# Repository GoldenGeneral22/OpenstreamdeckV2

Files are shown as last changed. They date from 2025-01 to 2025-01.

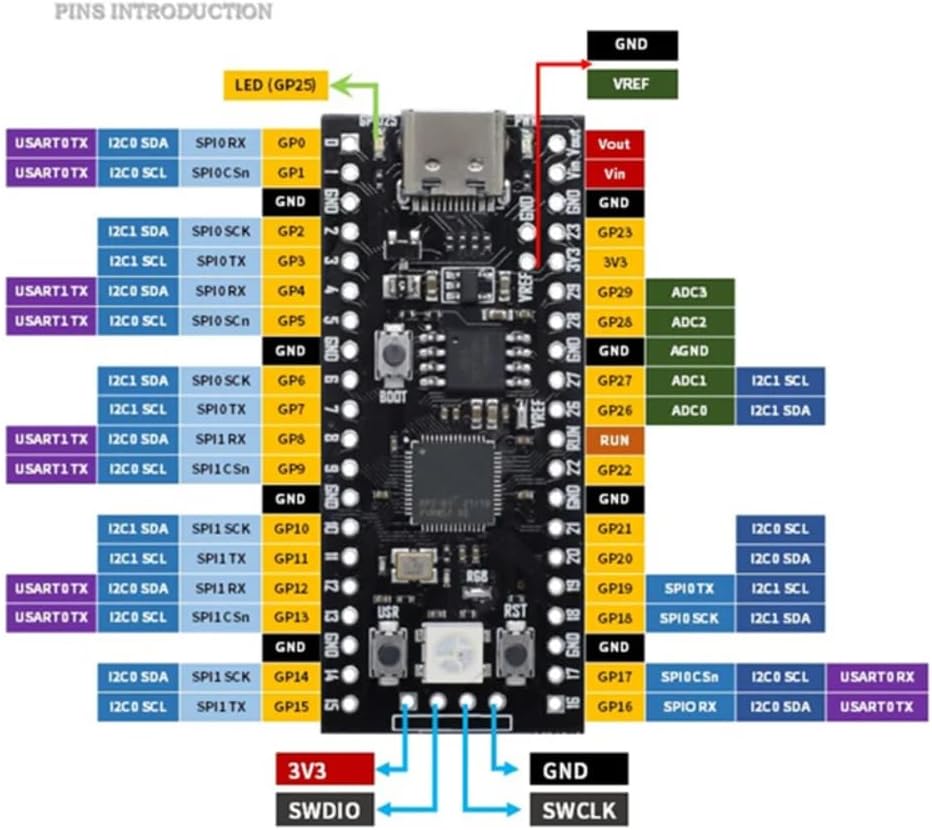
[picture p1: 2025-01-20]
Hardware/General/Dollatek Pinout.jpg

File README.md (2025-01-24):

# OpenstreamdeckV2: modular and open-source
A modular open-source 3D-printable Version of the Elgato streamdeck using 6 cherry-mx-style keyswitches(F13-F18) and a pressable KY-040 rotary encoder(volume increase, volume decrease, volume mute) as well as a RP2040 Microcontroller running circuitpython.

The area is divided into one bigger rectancular modul, used for the keyswitches and one smaller square modul, used for the rotary encoder.

To increase modularity and repairability only Jumper-Cables were used to connect to the RP2040 Microcontroller.

## External Works used:
### Software
Circuit diagram software used https://fritzing.org/

HID-Library used https://github.com/adafruit/Adafruit_CircuitPython_HID

USB-Library used https://docs.circuitpython.org/en/latest/shared-bindings/usb_hid/

### Hardware
RP2040 Microcontroller used https://amzn.eu/d/6dbKLKC

KY-040 rotary encoders used https://amzn.eu/d/2rxxnzF

Keyswitches used https://amzn.eu/d/dNDsguh

also used m3 screws, m3 thread inserts, female-to-female jumper cables, 3mm blue LEDs and resistors for the LEDs

### 3D-Prints
blank keycaps used https://www.thingiverse.com/thing:4186055 from CDante on Thingiverse.

encoder knob used https://www.thingiverse.com/thing:2797118 from tsw on Thingiverse.

The specific keycaps, the case and the modules were my own creation.

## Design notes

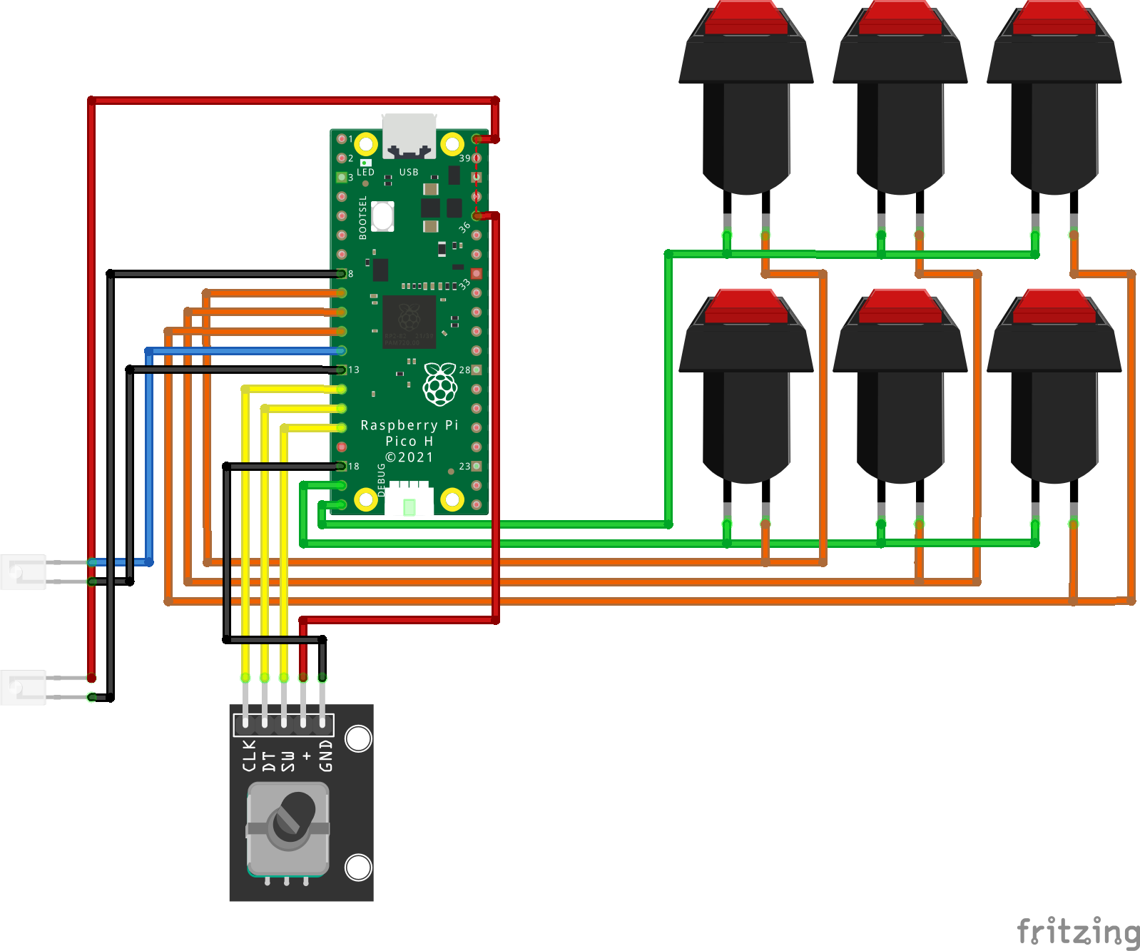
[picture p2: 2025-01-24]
Hardware/Circuit diagram/streamdeck_Steckplatine.png

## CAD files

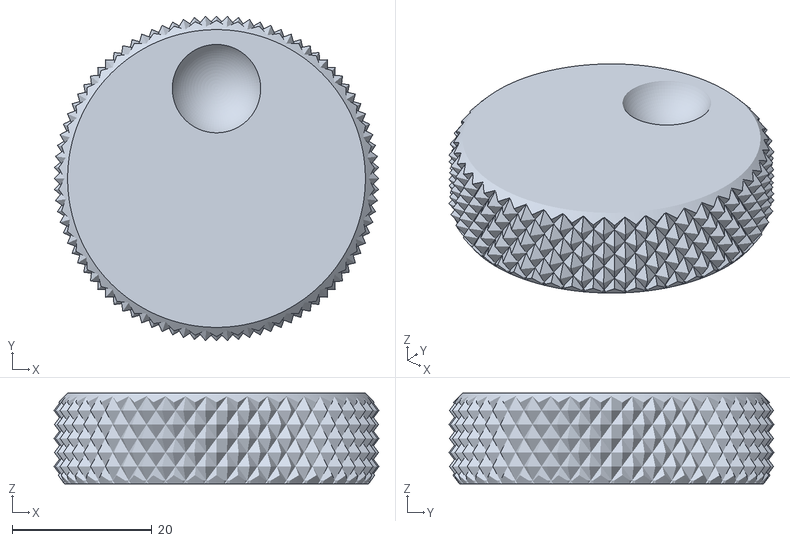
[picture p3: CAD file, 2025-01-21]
Hardware/3D Prints/EncoderKnob/rotary-encoder-knob_knurled.stl
46.5 x 46.5 x 13.0

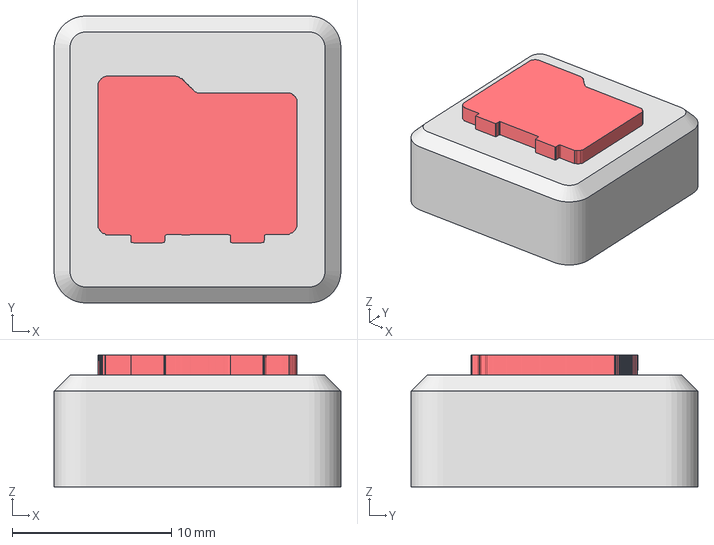
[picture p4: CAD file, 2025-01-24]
Hardware/3D Prints/Keycaps/Explorer Keycap.3mf
18.0 x 18.0 x 8.26 mm

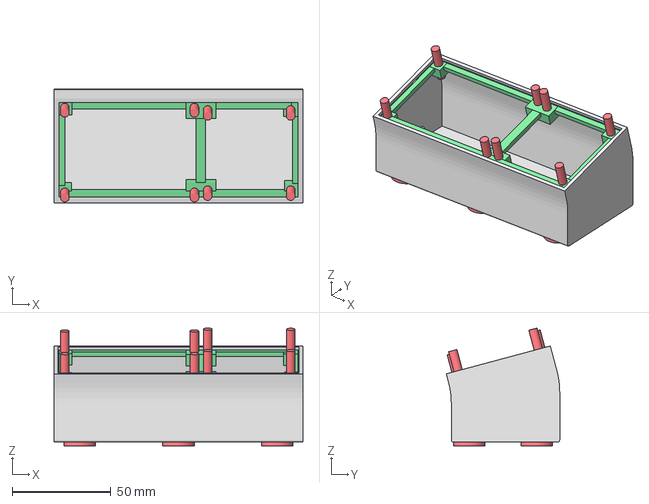
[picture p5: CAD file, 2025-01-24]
Hardware/3D Prints/MountingCase/CasePrototype v3.3mf
126.0 x 57.4 x 59.7 mm

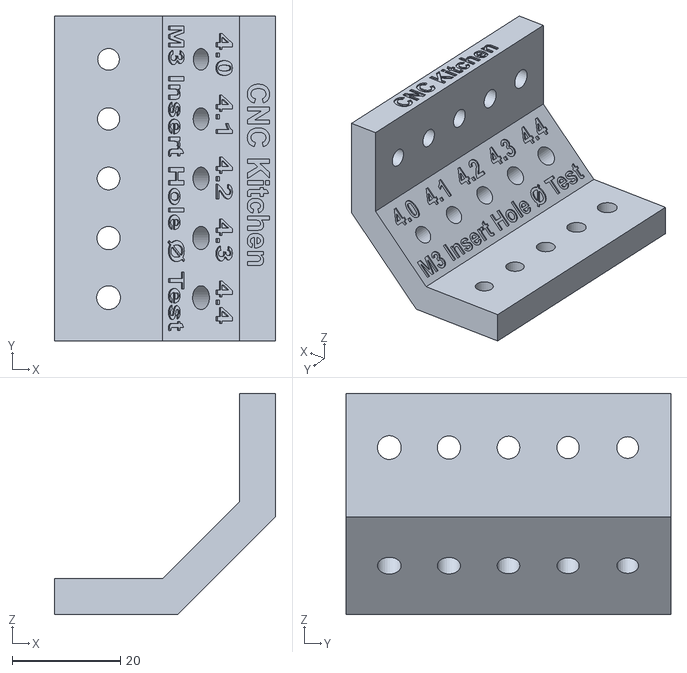
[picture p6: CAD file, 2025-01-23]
Hardware/3D Prints/Tests/InsertTest_M3.stl
40.8 x 60.0 x 40.8

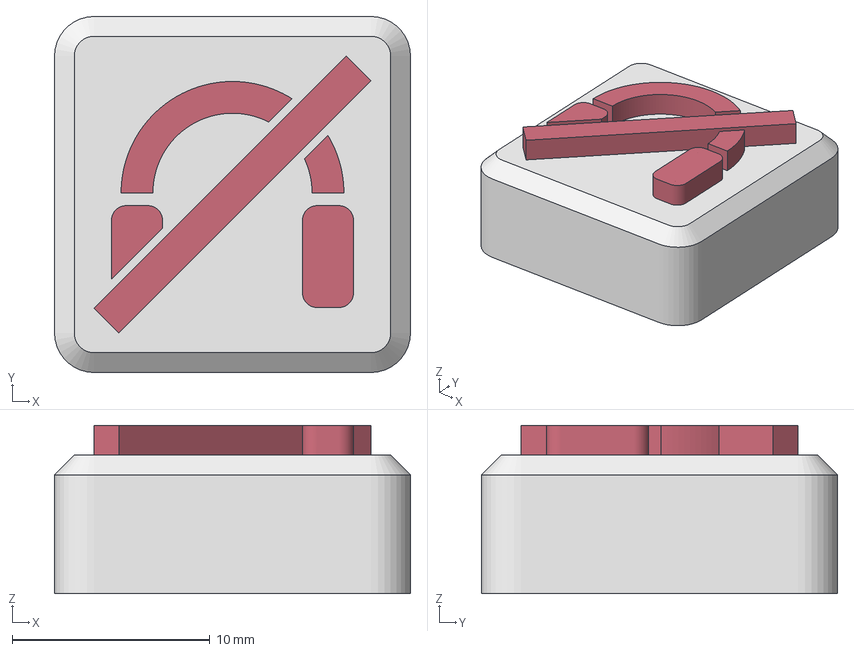
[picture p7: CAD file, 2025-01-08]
Hardware/3D Prints/Keycaps/Deafen Keycap.3mf
18.0 x 18.0 x 8.50 mm

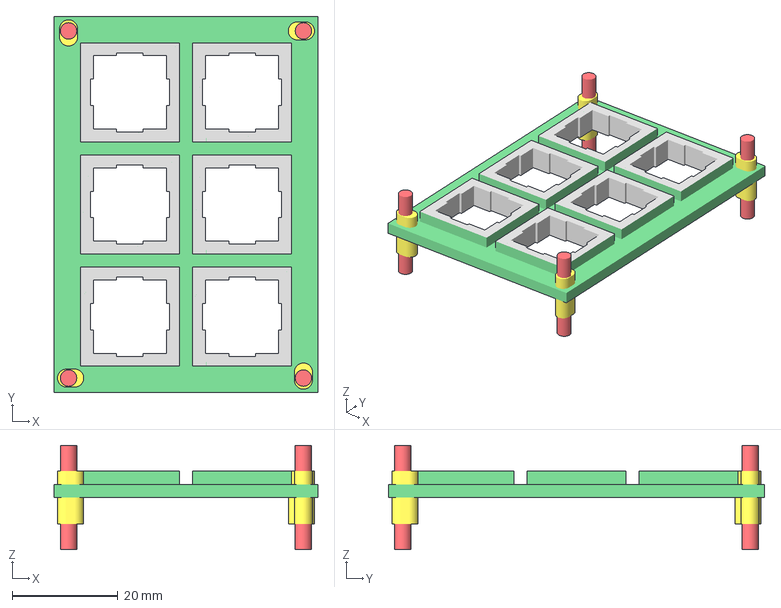
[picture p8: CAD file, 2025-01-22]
Hardware/3D Prints/MountingCase/Switchmount.3mf
49.9 x 71.1 x 19.7 mm

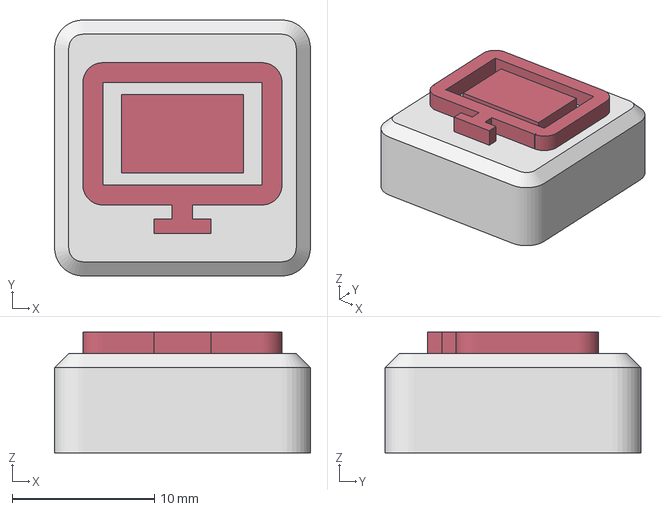
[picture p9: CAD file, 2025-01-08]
Hardware/3D Prints/Keycaps/Screenshare Keycap.3mf
18.0 x 18.0 x 8.50 mm

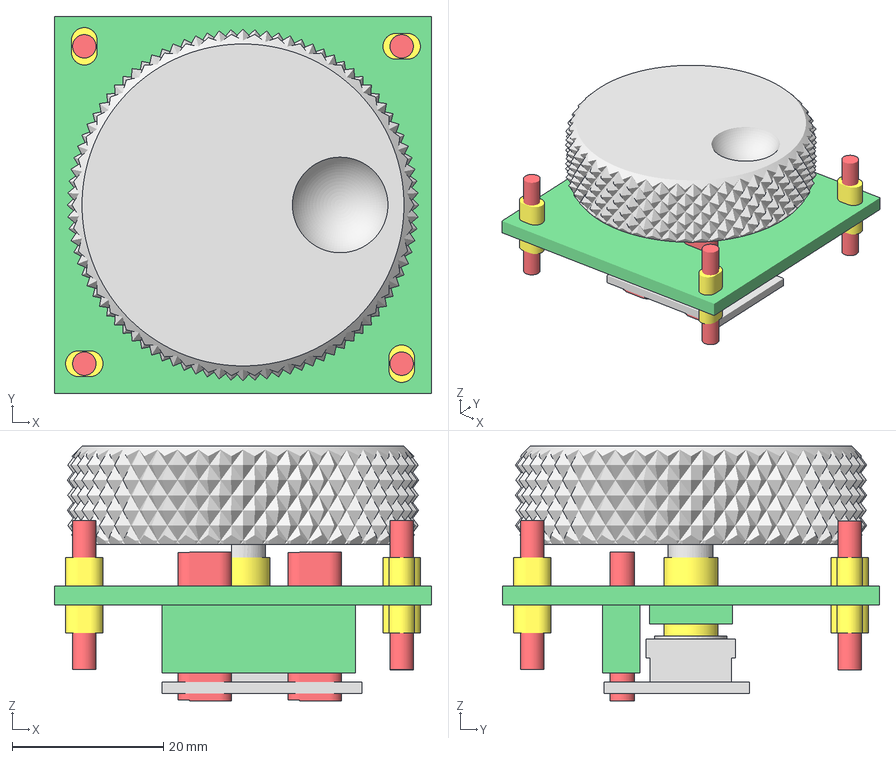
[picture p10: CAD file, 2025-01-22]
Hardware/3D Prints/MountingCase/EncoderMount.3mf
49.9 x 49.9 x 33.7 mm

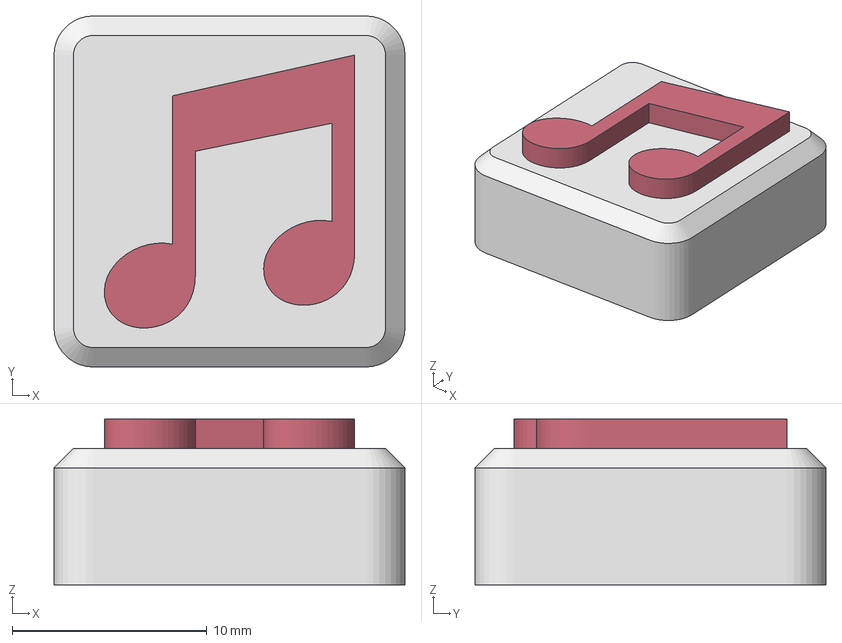
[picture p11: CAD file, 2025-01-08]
Hardware/3D Prints/Keycaps/Soundboard Keycap.3mf
18.0 x 18.0 x 8.50 mm

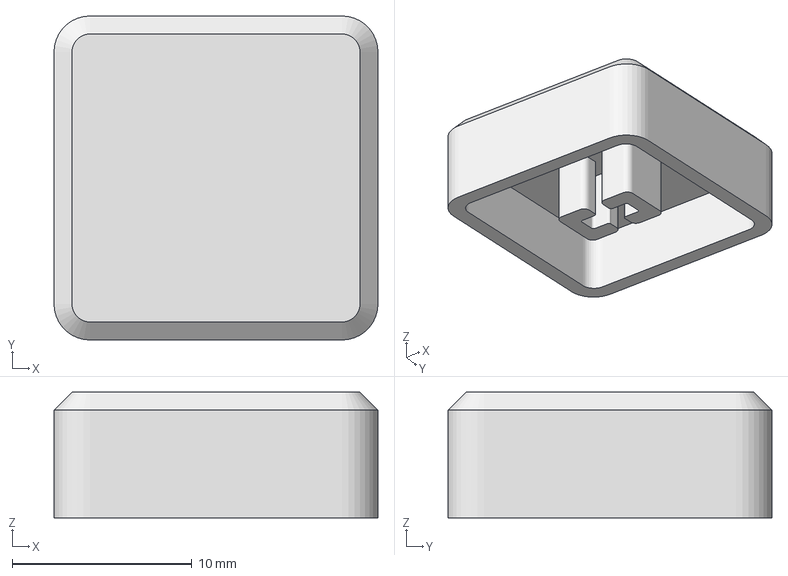
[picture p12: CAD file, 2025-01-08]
Hardware/3D Prints/Keycaps/Blank Keycap.3mf
18.0 x 18.0 x 7.00 mm

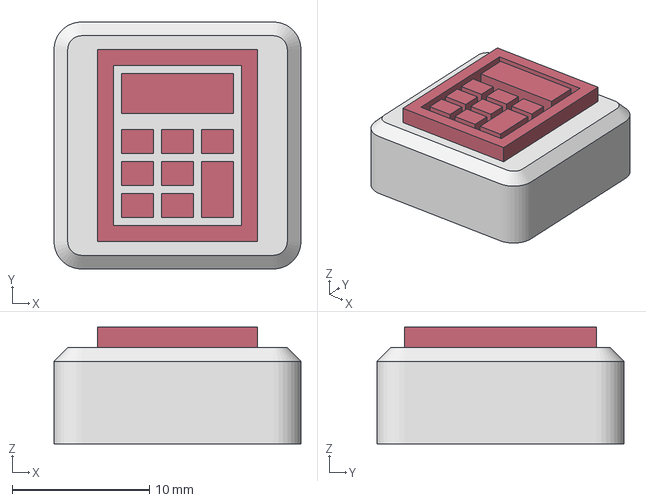
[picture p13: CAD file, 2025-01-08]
Hardware/3D Prints/Keycaps/Calculator Keycap.3mf
18.0 x 18.0 x 8.50 mm

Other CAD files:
Hardware/3D Prints/Keycaps/Disconnect Keycap.3mf
Hardware/3D Prints/Keycaps/Mute Keycap.3mf
Hardware/3D Prints/Keycaps/Calculator Keycap.stl
Hardware/3D Prints/Keycaps/Deafen Keycap.stl
Hardware/3D Prints/Keycaps/Disconnect Keycap.stl
Hardware/3D Prints/Keycaps/Explorer Keycap.stl
Hardware/3D Prints/Keycaps/Mute Keycap.stl
Hardware/3D Prints/Keycaps/Screenshare Keycap.stl
Hardware/3D Prints/Keycaps/Soundboard Keycap.stl
Hardware/3D Prints/MountingCase/CasePrototype v3.stl
Hardware/3D Prints/MountingCase/EncoderMount.stl
Hardware/3D Prints/MountingCase/Switchmount.stl

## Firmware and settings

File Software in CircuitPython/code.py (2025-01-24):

#importing relevant libraries
import time
import board
import digitalio
import rotaryio
import usb_hid
from adafruit_hid.keyboard import Keyboard
from adafruit_hid.keycode import Keycode
from adafruit_hid.consumer_control import ConsumerControl
from adafruit_hid.consumer_control_code import ConsumerControlCode

# Custom "Enum" class replacement for CircuitPython
class Keys:
    _members = {
        'Null': 0,
        'F13': 1,
        'F14': 2,
        'F15': 3,
        'F16': 4,
        'F17': 5,
        'F18': 6,
        'Mute': 7,
        'Vol_Decrease': 8,
        'Vol_Increase': 9,
    }
    @classmethod
    def get_by_value(cls, value):
        for name, val in cls._members.items():
            if val == value:
                return name
        return None
    @classmethod
    def get_value(cls, name):
        return cls._members.get(name, None)
    @classmethod
    def items(cls):
        return cls._members.items()

# Definition of pins for RPI Pico clone
inputLed = digitalio.DigitalInOut(board.GP9)
inputLed.direction = digitalio.Direction.OUTPUT

encoderButton = digitalio.DigitalInOut(board.GP12)
encoderButton.direction = digitalio.Direction.INPUT
encoderButton.pull = digitalio.Pull.UP

outputLanes = [digitalio.DigitalInOut(board.GP15), digitalio.DigitalInOut(board.GP14)]
for lane in outputLanes:
    lane.direction = digitalio.Direction.OUTPUT

detectLanes = [digitalio.DigitalInOut(board.GP6), digitalio.DigitalInOut(board.GP7), digitalio.DigitalInOut(board.GP8)]
for lane in detectLanes:
    lane.direction = digitalio.Direction.INPUT
    lane.pull = digitalio.Pull.UP

# Definition of relevant variables, etc.
kbd = Keyboard(usb_hid.devices)
cc = ConsumerControl(usb_hid.devices)

inputLedDelay = 0.05
rows = 2
columns = 3

encoder = rotaryio.IncrementalEncoder(board.GP10, board.GP11)
last_position = encoder.position

# setup() runs once at startup
def setup():
    ledBurst()
    time.sleep(inputLedDelay)
    ledBurst()
    time.sleep(inputLedDelay)
    ledBurst()

# ledBurst() lets the inputLed blink once
def ledBurst() -> None:
    inputLed.value = True
    time.sleep(inputLedDelay)
    inputLed.value = False

# checkForInput() is repeated infinitely by the main loop
def checkForInput():
    for row in outputLanes:
        row.value = True
        for colum in detectLanes:
            if not colum.value:
                enum_value = outputLanes.index(row) * 3 + detectLanes.index(colum) + 1
                return Keys.get_by_value(enum_value)
        row.value = False

    if not encoderButton.value:
        return 'Mute'
    
    global last_position
    position = encoder.position
    if position < last_position:
        last_position = position
        return 'Vol_Decrease'
    elif position > last_position:
        last_position = position
        return 'Vol_Increase'
    
    return 'Null'

# processInput() sends the Keycode to the Computer
def processInput(input):
    if input == 'F13':
        kbd.press(Keycode.WINDOWS)
        kbd.press(Keycode.E)
        time.sleep(.09)
        kbd.release(Keycode.WINDOWS)
        kbd.release(Keycode.E)
        return
    elif input == 'F14':
        kbd.send(Keycode.F14)
        return
    elif input == 'F15':
        kbd.send(Keycode.F15)
        return
    elif input == 'F16':
        kbd.press(Keycode.CONTROL)
        kbd.press(Keycode.LEFT_ALT)
        kbd.press(Keycode.LEFT_SHIFT)
        kbd.press(Keycode.F12)
        time.sleep(.09)
        kbd.release(Keycode.CONTROL)
        kbd.release(Keycode.LEFT_ALT)
        kbd.release(Keycode.LEFT_SHIFT)
        kbd.release(Keycode.F12)
        return
    elif input == 'F17':
        kbd.send(Keycode.F17)
        return
    elif input == 'F18':
        kbd.send(Keycode.F18)
        return
    elif input == 'Mute':
        cc.send(ConsumerControlCode.MUTE)
        return
    elif input == 'Vol_Decrease':
        cc.send(ConsumerControlCode.VOLUME_DECREMENT)
        return
    elif input == 'Vol_Increase':
        cc.send(ConsumerControlCode.VOLUME_INCREMENT)
        return
    else:
        return

# loop() runs as long as the microcontroller has power
def loop():
    activeButton = None
    while True:
        input = checkForInput()
        if input != 'Null' and activeButton is None:
            activeButton = input
            print(input)
            processInput(input)
            ledBurst()
        elif input == 'Null' and activeButton is not None:
            activeButton = None

# main() is the program's main thread
def main():
    setup()
    loop()    
main()

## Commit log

2025-01-08 Added different Keycaps
    [Blank Keycap.3mf, Calculator Keycap.3mf, Calculator.stl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]
2025-01-08 Added TestMount
    [Screenshare Keycap.stl, TestMount.3mf]
2025-01-09 Changed Stuff
    [Calculator Keycap.stl, Deafen Keycap.stl, Disconnect Keycap.stl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]
2025-01-20 Added Base Layer for Rotarty Encoder Intergration for Volume Control
    [Tastatur.fzz, TestMount.3mf, TestMount.stl]
2025-01-21 Added and updated 3d-Printfiles
    [Case.3mf, EncoderMount.3mf, Switchmount.3mf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]
2025-01-22 Added and Updated 3D Models
    [Blank Keycap.3mf, Calculator Keycap.3mf, Calculator Keycap.stl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]
2025-01-23 Added Test for Inserts
    [CasePrototype v3.3mf, CasePrototype v3.stl, InsertTest_M3.stl]
2025-01-24 Updated 3d-Models
    [CasePrototype v3.3mf, CasePrototype v3.stl]
2025-01-24 added png of circuit diagram
    [Tastatur.fzz, streamdeck.fzz]
2025-01-24 added different shortcut
    exchanged Soundboard Key with File Explorer Key, includes 3d-printfiles
    [Explorer Keycap.3mf, Explorer Keycap.stl]
